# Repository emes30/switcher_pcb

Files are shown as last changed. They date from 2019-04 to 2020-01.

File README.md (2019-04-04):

# Switcher 2.0 – 2 Channel WiFi Open Source Switch
This is fork from [this project](https://github.com/hborisov/switcher_pcb).
I've added support for two independent relays, two buttons and DS18B20 digital thermometer. 
It is compatibile with [Sonoff-Tasmota](https://github.com/arendst/Sonoff-Tasmota) firmware.

## Disclaimer
:warning: This device is meant to connect to AC MAINS. Be careful, if you have no experience, ask someone who has to assist you.

## Design
The board size is 46x46mm it shoud fit into standard electrical wall junction box where it is meant to be installed.

## Connections
Connections are very simple. 
1. Connect AC mains L, N to power line.
2. Connect your devices to OUT_1 and OUT_2. Maximum output power output is 400W. It is enough for light sources. It should not be used for wall sockets. For outputs above 200W consider attaching heatsinks to BT136's to dissipate heat.
3. Connect BTN_1 and BTN_2 to momentary buttons, notice that there is no high voltage on these buttons.

## Programming WiFi module
Board is designed to work with ESP8266 module ESP-01S, this is simplest and cheapest ESP module. Unfortunatelly you cannot program module in place, as there is no space for required pinheader. You should flash chip with [Sonoff-Tasmota](https://github.com/arendst/Sonoff-Tasmota) firmware and choose Sonoff Generic device. You need to program module only once, then you can update via web interface.

## Sensor
There is pinheader where you can connect 1-Wire DS18B20 digital thermometer. It uses BTN_1 pin so you can't use both DS18B20 and BTN_1.

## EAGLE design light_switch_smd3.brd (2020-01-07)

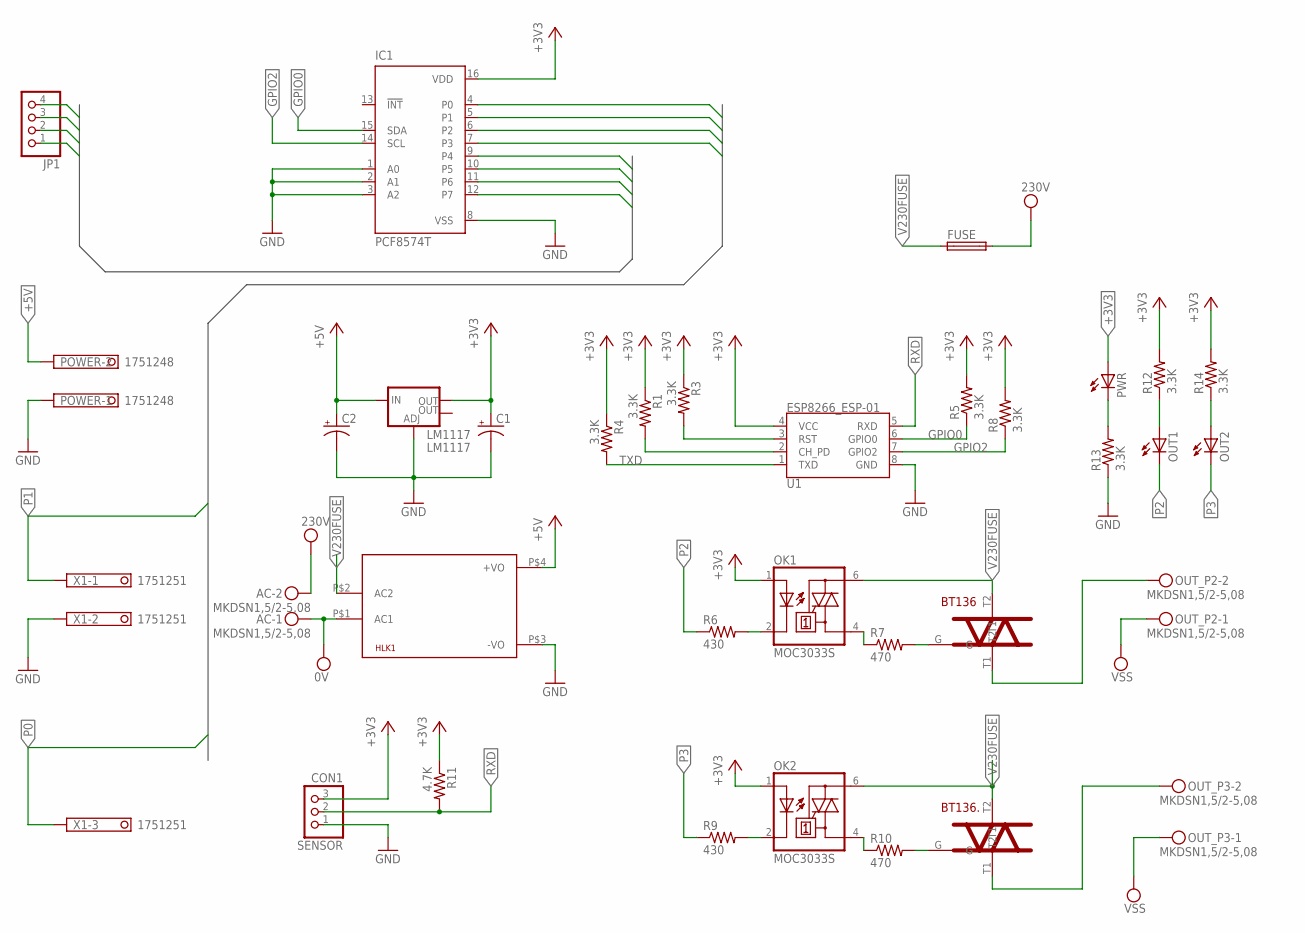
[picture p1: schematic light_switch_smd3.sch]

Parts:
AC: MKDSN1,5/2-5,08
BT136, BT136.: BT136; BT136-PKG
C1, C2: 10uF; A/3216-18R
FUSE: TE5
HLK1: HLK-PM013W; HLK-PM01
IC1: PCF8574T; SO16W
JP1: PINHD-1X4; 1X04
LM1117: LM1117; SOT223
OK1, OK2: MOC3033S; DIL6-SMD
OUT1, OUT2: LEDSML1206; SML1206
OUT_P2, OUT_P3: MKDSN1,5/2-5,08
POWER: 1751248
PWR: LEDSML1206; SML1206
R1, R3, R4, R5, R8, R12, R13, R14: 3.3K; R1206
R6, R9: 430; R1206
R7, R10: 470; R1206
R11: 4.7K; R1206
SENSOR: CON1; 1X03
U1: ESP8266_ESP-01
X1: 1751251

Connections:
+3V3: C1.+, IC1.16 (VDD), LM1117.2 (OUT), OK1.1 (A), OK2.1 (A), PWR.A, R1.1, R3.1, R4.1, R5.2, R8.2, R11.1, R12.2, R14.2, SENSOR.3, U1.4 (VCC)
+5V: C2.+, HLK1.P$4 (+VO), LM1117.3 (IN), POWER.2
CH_PD: R1.2, U1.2 (CH_PD)
GND: C1.-, C2.-, HLK1.P$3 (-VO), IC1.1 (A0), IC1.2 (A1), IC1.3 (A2), IC1.8 (VSS), LM1117.1 (ADJ), POWER.1, R13.1, SENSOR.1, U1.8 (GND), X1.2
GPIO0: IC1.15 (SDA), R5.1, U1.6 (GPIO0)
GPIO2: IC1.14 (SCL), R8.1, U1.7 (GPIO2)
unnamed: PWR.C, R13.2
unnamed: OK2.2 (C), R9.2
unnamed: OK2.4 (A1), R10.1
unnamed: BT136.T1, OUT_P2.2
unnamed: OK1.2 (C), R6.2
unnamed: BT136.G, R7.2
unnamed: OK1.4 (A1), R7.1
unnamed: BT136..T1, OUT_P3.2
unnamed: OUT1.A, R12.1
unnamed: OUT2.A, R14.1
unnamed: BT136..G, R10.2
P0: IC1.4 (P0), X1.3
P1: IC1.5 (P1), X1.1
P2: IC1.6 (P2), OUT1.C, R6.1
P3: IC1.7 (P3), OUT2.C, R9.1
P4: IC1.9 (P4), JP1.1
P5: IC1.10 (P5), JP1.2
P6: IC1.11 (P6), JP1.3
P7: IC1.12 (P7), JP1.4
RST: R3.2, U1.3 (RST)
RXD: R11.2, SENSOR.2, U1.5 (RXD)
TXD: R4.2, U1.1 (TXD)
V230FUSE: BT136.T2, BT136..T2, FUSE.1, HLK1.P$2 (AC2), OK1.6 (A2), OK2.6 (A2)
VPP: AC.2, FUSE.2
VSS: AC.1, HLK1.P$1 (AC1), OUT_P2.1, OUT_P3.1

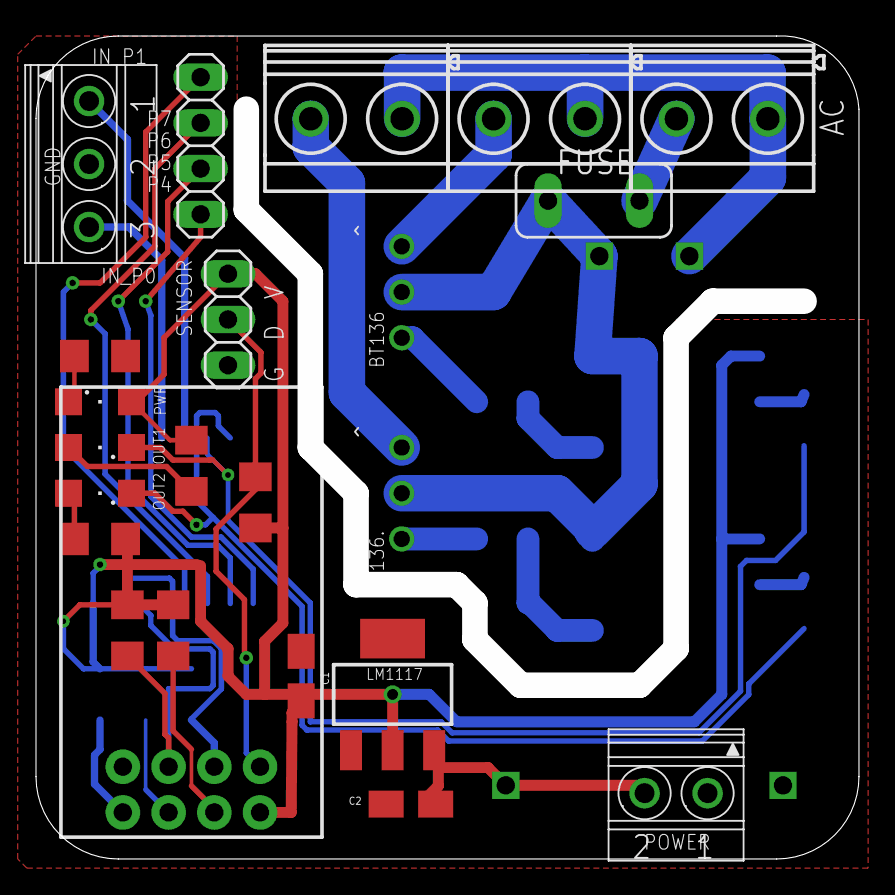
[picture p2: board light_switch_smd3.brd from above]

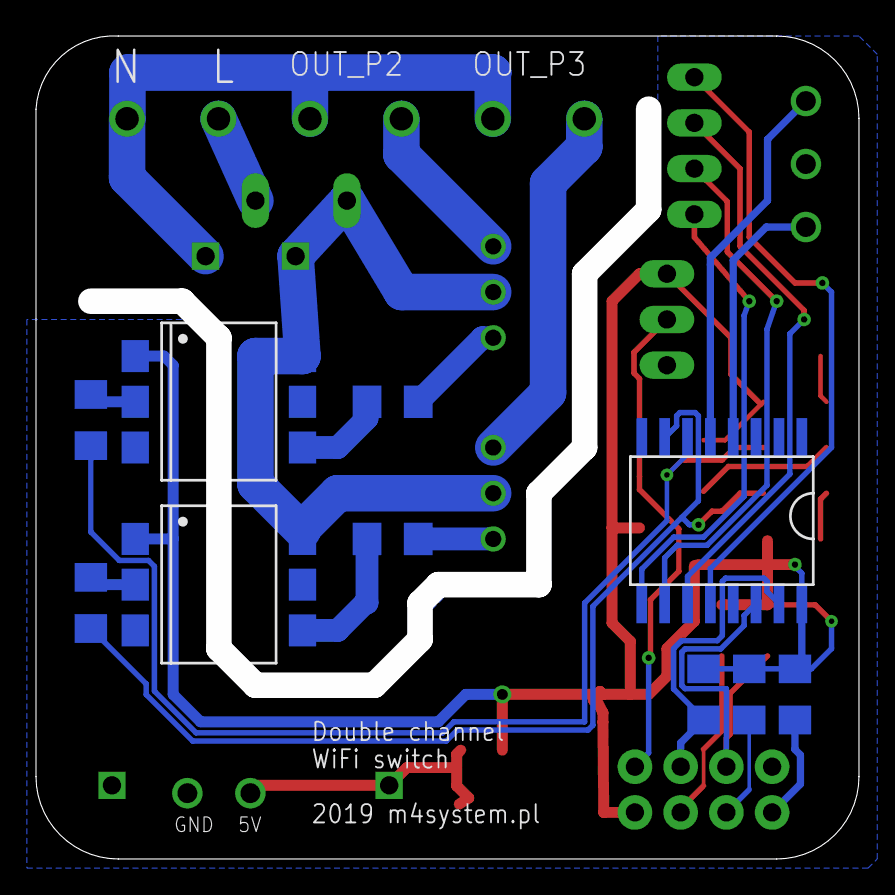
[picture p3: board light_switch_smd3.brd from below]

Board: 2 copper layers, 45.7 x 45.7 mm, 34 parts (10 on the bottom side), 31 nets.

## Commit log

2019-02-11 major update. added second relay circuit, redesigned board
    [light_switch_smd3.brd, light_switch_smd3.sch]
2019-02-11 almost ready for production. some descriptions needs adjusting.
    [light_switch_smd3.brd, light_switch_smd3.sch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]
2019-02-11 minor bugs fixed
    [light_switch_smd3.brd, light_switch_smd3.sch]
2019-02-11 sligthly bigger smd parts, for easier soldering
    [light_switch_smd3.brd, light_switch_smd3.sch]
2019-02-25 kosmetyczne poprawki, wersja wysłana do produkcji
    [light_switch_smd3.brd, light_switch_smd3.sch]
2019-02-25 added missing sensor data connection
    [light_switch_smd3.brd, light_switch_smd3.sch]
2019-02-25 small fixes to be more ERC friendly
    [light_switch_smd3.brd, light_switch_smd3.sch]
2019-04-04 routed missed track
    [light_switch_smd3.brd]
2019-04-05 added LEDs, more rounded corners, +5V power connector
    [light_switch_smd3.brd, light_switch_smd3.sch]
2019-05-14 added pcf8574 due to undefined state of GPIOs during boot
    [light_switch_smd3.brd, light_switch_smd3.sch]
2019-05-15 DRC checked, no airwires
    [light_switch_smd3.brd, light_switch_smd3.sch]
2020-01-06 added pinheader and small fixes
    [light_switch_smd3.brd, light_switch_smd3.sch]
2020-01-07 descriptions adjusted
    [light_switch_smd3.brd, light_switch_smd3.sch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]

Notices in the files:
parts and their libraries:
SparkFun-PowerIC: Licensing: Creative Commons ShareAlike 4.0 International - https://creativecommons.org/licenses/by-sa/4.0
